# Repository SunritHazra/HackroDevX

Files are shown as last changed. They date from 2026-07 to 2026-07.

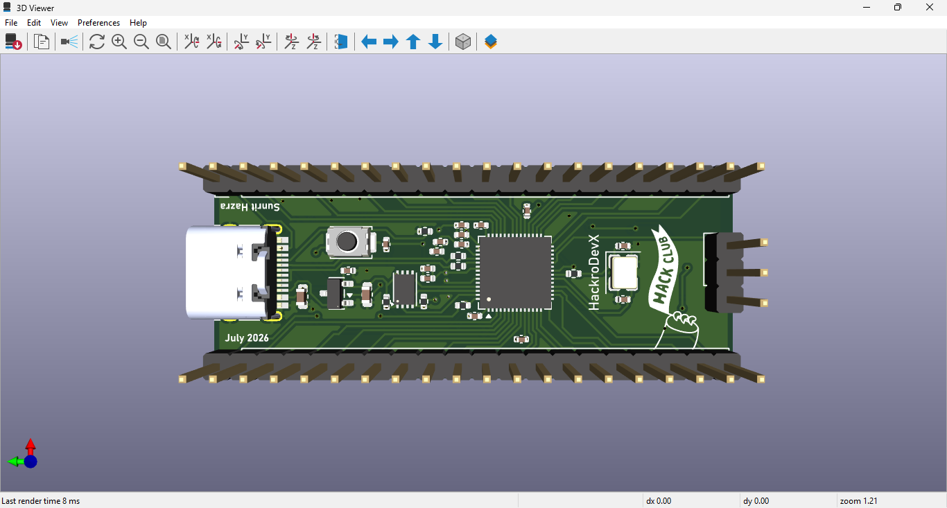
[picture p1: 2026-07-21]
Gallery/KiCad PCBA Render.png

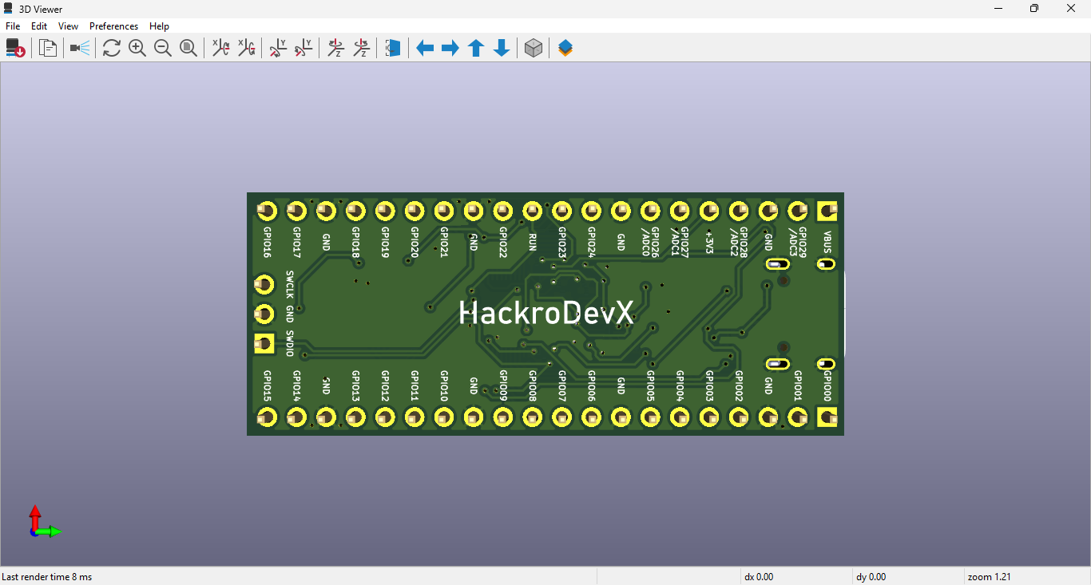
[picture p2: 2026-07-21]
Gallery/KiCad PCBA Back Side.png

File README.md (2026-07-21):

# HackroDevX

An open-source RP2040 development board with USB-C power/programming, onboard QSPI flash, and a Raspberry Pi Pico-compatible pinout. Built by following Hack Club's ["Custom Devboard"](https://blueprint.hackclub.com/starter-projects/devboard) starter project guide, entirely in KiCad. This is my first custom PCB from schematic to fabrication.

> Full day-by-day design log, decisions, and mistakes: [Engineering Log.md](https://github.com/SunritHazra/HackroDevX/blob/main/Engineering%20Log.md) (see also [JOURNAL.md](https://github.com/SunritHazra/HackroDevX/blob/main/JOURNAL.md) and [Fabrication Log.md](https://github.com/SunritHazra/HackroDevX/blob/main/Fabrication%20Log.md))

**Project stats:** 5 build-log days · ~25h 00m total design time · 100% designing progress, 0% building progress (as of the latest journal entry — board is ordered for PCBA, not yet assembled)

**On the name:** Follows the author's personal naming convention for electronics projects — "Hackro" as the base word, a short form of the project's defining trait ("Dev", for devboard), and a single trailing letter — giving **HackroDevX**.

---

## Renders

### Top View



### 45° View



### Bottom Corner View



---

## Hardware Architecture

### 1. Electrical Schematic

Full Schematic



The schematic follows the five functional blocks the guide breaks a devboard into: power/decoupling, USB-C, the crystal oscillator, QSPI flash storage, and the I/O breakout, all wired around a central RP2040.

**Power & decoupling:** One 0.1uF decoupling capacitor per RP2040 VDD pin — eight on the 3.3V IOVDD rail, two on the 1.1V DVDD rail — plus a 1uF bulk capacitor on each rail to smooth larger ripples. Power labels face up, ground labels face down, per standard schematic convention. [This](https://github.com/user-attachments/assets/96dde608-219d-472a-9682-96a95f16b071) is the power and decopuling.

**USB-C & step-down:** A USB-C receptacle with SHIELD/GND tied to ground, CC1/CC2 pulled down through 5.1KΩ resistors so the port negotiates power delivery, and the D+/D- lines routed through 27Ω termination resistors into the RP2040's USB_DP/USB_DM pins (set to bidirectional global labels). VBUS is stepped down from 5V to 3.3V using an **MCP1700x-330xxTT** LDO (swapped in from the guide's larger NCP1117-3.3_SOT223 for a smaller footprint, at the cost of a lower 250mA current limit), with 10uF bulk capacitors bracketing it. [This](https://github.com/user-attachments/assets/9e6f4866-57e1-4350-a7fc-b4eadb88d3cd) is the USB-C and step down.

**Crystal oscillator:** A 12MHz crystal (Y1) with two load capacitors on its I/O pins (bumped from the guide's 15pF to 33pF to match the load capacitance of the specific crystal part used), pins 2/4 tied to GND, and a 1KΩ damping resistor on XOUT to protect the crystal and keep the clock signal clean. [This](https://github.com/user-attachments/assets/4e26f85b-4016-400b-a56b-7d17701c3016) is the crystal ossilator.

**QSPI flash:** Since the RP2040 has no onboard flash, a quad-SPI flash IC is wired up with global labels matching the RP2040's QSPI pins, a 0.1uF decoupling cap on VCC, a 10KΩ pull-up on CS, and a BOOTSEL push button in series with a 1KΩ current-limiting resistor to GND — dropping the board into BOOTSEL/mass-storage mode on boot. [This](https://github.com/user-attachments/assets/fbd2d72e-f6a8-4ca6-835c-226b7e35d64e) is the onboard QSPI flash.

**I/O breakout:** TESTEN tied to GND (factory-test-only pin), and every remaining GPIO plus SWCLK/SWDIO broken out across two 1x20 headers and one 1x3 header, laid out to match the Raspberry Pi Pico pinout. VSYS, 3V3_EN, and ADC_VREF were skipped since there's no battery support, freeing up pins for extra GPIOs — including GPIO29 (ADC-capable) in place of the unused GPIO25. [This](https://github.com/user-attachments/assets/0c8a8f67-9cef-4537-8e4d-47fdbf4ebf10) is the I/O pins broken out.

### 2. Footprints

- **RP2040:** `QFN-56-1EP_7x7mm_P0.4mm_EP3.2x3.2mm`, straight from the datasheet.
- **Decoupling capacitors:** `0402` for all small signal capacitors.
- **Decopuling resistors:** `0402` for all small resistors.
- **Bulk (10uF) capacitors:** `0603`, for the extra physical room they need.
- **USB-C receptacle:** `USB_C_Receptacle_HRO_TYPE-C-31-M-12` — JLCPCB has no true basic-library USB-C part.
- **Header pins:** `PinHeader_1x20_P2.54mm_Vertical` (×2) and `PinHeader_1x03_P2.54mm_Vertical`.
- **Boot button:** `SW_Push_SPST_NO_Alps_SKRK`, a compact SMD footprint in JLCPCB's basic library.
- **Crystal:** `Crystal_SMD_3225-4Pin_3.2x2.5mm`, also a JLCPCB basic part — pin 1/3 orientation double-checked against the datasheet.
- **LDO:** `MCP1700x-330xxTT` (SOT-23), swapped from the NCP1117 for size.
- **Flash:** `W25Q16JVZPIQ TR` in the `Winbond_USON-8-1EP_3x2mm_P0.5mm_EP0.2x1.6mm` package — the same flash chip used on the real Pi Pico, swapped from the datasheet's larger W25Q128JVS.

### 3. Printed Circuit Board Assembly

Designed for rugged reliability and high-profile ergonomics using the custom footprints above.

KiCad PCB Window



KiCad PCB Render



KiCad PCBA Render



KiCad PCB Back Side



KiCad PCBA Back Side



- **Design files:** [`/PCBA`](./PCBA)

## Design Notes

**Board Size:** The board outline follows the guide's Pico-shaped form factor, sized **21mm × 51.5mm** (slightly longer than the guide's reference 21×51mm outline).

**Crystal load capacitance:** swapping to a different crystal part than the guide's reference meant the load capacitors had to be bumped from 15pF to 33pF to match its datasheet load capacitance.

**ERC net conflict:** an early wiring mistake merged the LDO's output and the RP2040's VREG_VOUT onto the same net (both flagged as power outputs), caused by using a slightly different LDO symbol than the guide's. Fixed by re-tracing the actual intended connections.

**Differential pair skew:** the USB D+/D- traces were initially routed without matching their lengths, resulting in a 6.5mm+ mismatch against a ~0.2mm budget — fixed by rerouting them as a proper differential pair.

**Silkscreen:** reference designators and values were batch-moved from the `F.Fab` layer to `F.Silkscreen` using KiCad's footprint text field batch update (filtered by layer, applied to functional text items). Less-useful `C#`/`R#` labels on small passives were deleted for a cleaner look, and bottom-side GPIO labels were checked for correct mirroring/orientation. The Hack Club "Orpheus" flag logo was thresholded through KiCad's Image Converter and placed on the silkscreen next to a `HackroDevX` text label and the author's name.**Silkscreen:** reference designators and values were batch-moved from the `F.Fab` layer to `F.Silkscreen` using KiCad's footprint text field batch update (filtered by layer, applied to functional text items). Less-useful `C#`/`R#` labels on small passives were deleted for a cleaner look, and bottom-side GPIO labels were checked for correct mirroring/orientation. The Hack Club "Orpheus" flag logo was thresholded through KiCad's Image Converter and placed on the silkscreen next to a `HackroDevX` text label and the author's name.

---

## Fabrication

- **Electrical Rule Check (ERC)** run after the schematic was completed.
- **Design Rule Check (DRC)** run after routing and ground pour, with thermal-relief/clearance errors resolved before export.
- **Gerber export:** full fabrication output (gerbers, drill files, footprint position files) exported from KiCad `9.0.7`.
- **CPL/BOM formatting for JLCPCB:** the CPL (`top-pos`) file headers were renamed `Ref → Designator`, `PosX → Mid X`, `PosY → Mid Y`, `Rot → Rotation`, `Side → Layer`, and the BOM's `Designation` column renamed to `Comment`, per JLCPCB's expected format.
- **Ordered:** production zip uploaded to JLCPCB with PCBA added for a batch of 5 assembled boards. Most parts auto-matched (RP2040 QFN-56, MCP1700x-330xxTT, USB-C receptacle, crystal, resistors, caps); the flash memory needed a manual match to JLCPCB's in-stock `W25Q16JVUXQTR` (functionally equivalent to the designed `W25Q16JVZPIQ TR`). Pin headers were left off the assembled parts list to hand-solder separately instead of paying per-part assembly fees.

Design files: [`/PCBA`](https://github.com/SunritHazra/HackroDevX/tree/main/PCBA)

---

## Bill of Materials (BOM)

JLCPCB BOM



JLCPCB BOM Tool - BOM Matching



Full sourcing sheet: [`/Bill of Materials`](https://github.com/SunritHazra/HackroDevX/tree/main/Bill%20of%20Materials)

### Electronics & PCB (SMD)

- **1x** PCB (21mm × 51.5mm, Pico-shaped outline)
- **1x** Raspberry Pi RP2040 SoC (QFN-56)
- **1x** W25Q16JVZPIQ TR QSPI flash memory
- **1x** MCP1700x-330xxTT LDO (3.3V, SOT-23)
- **1x** USB-C receptacle (HRO TYPE-C-31-M-12)
- **1x** 12MHz crystal oscillator (SMD 3225-4Pin)
- **1x** SPST push button (BOOTSEL)
- Decoupling capacitors (0402: 0.1uF ×10, 1uF ×2), bulk capacitors (0603: 10uF ×2), termination resistors (27Ω ×2), pull-up/pull-down/damping resistors (5.1KΩ, 10KΩ, 1KΩ)

### Hardware (THT)

- **2x** `PinHeader_1x20_P2.54mm_Vertical`
- **1x** `PinHeader_1x03_P2.54mm_Vertical`

### Sourcing

| Component | Vendor  |
| --- | --- |
| PCB Fabrication & PCBA | JLCPCB  |

JLCPCB Order



--

## AI as a Research & Documentation Aid

The schematic, footprint selection, PCB layout, routing, and all fabrication decisions were done manually by following the Hack Club guide and the RP2040 datasheet. AI tools were used only in a supporting role — for example, researching general approaches to fixing a stubborn DRC thermal-relief/clearance error, and for helping structure and write up this documentation.

> **Project Integrity:** All schematic wiring, footprint selection, PCB routing, and fabrication file prep were done manually in KiCad by following the Hack Club Devboard guide and the RP2040 datasheet. AI was used only for research, troubleshooting suggestions, and documentation help.

---

## License

This project is licensed under the MIT License — see the [LICENSE](https://github.com/SunritHazra/HackroDevX/blob/main/LICENSE) file for details.

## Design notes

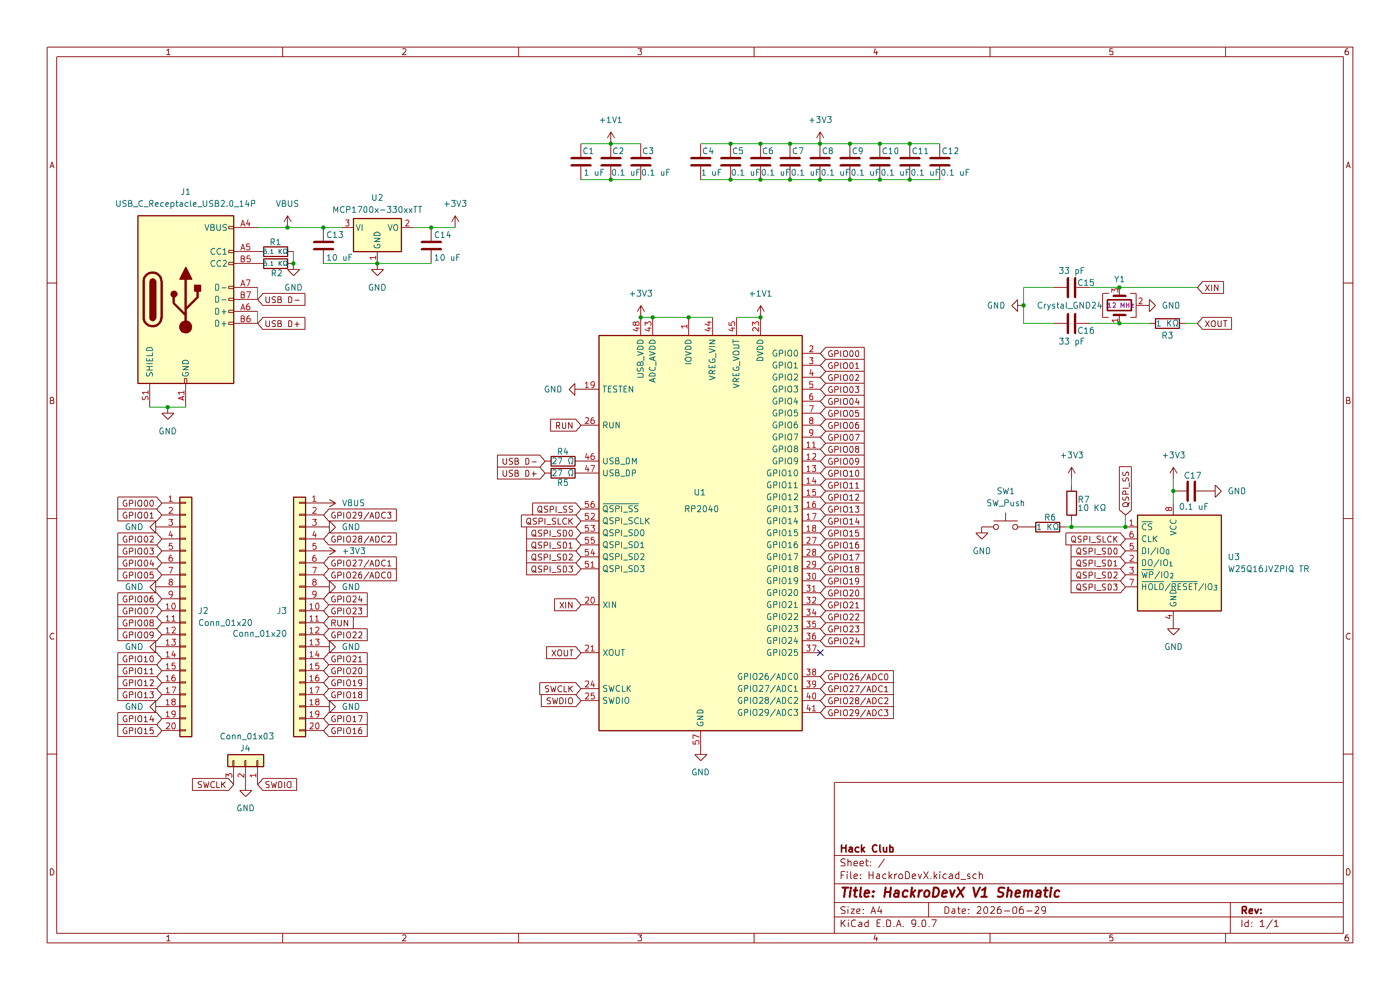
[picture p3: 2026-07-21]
Gallery/Schematic.png

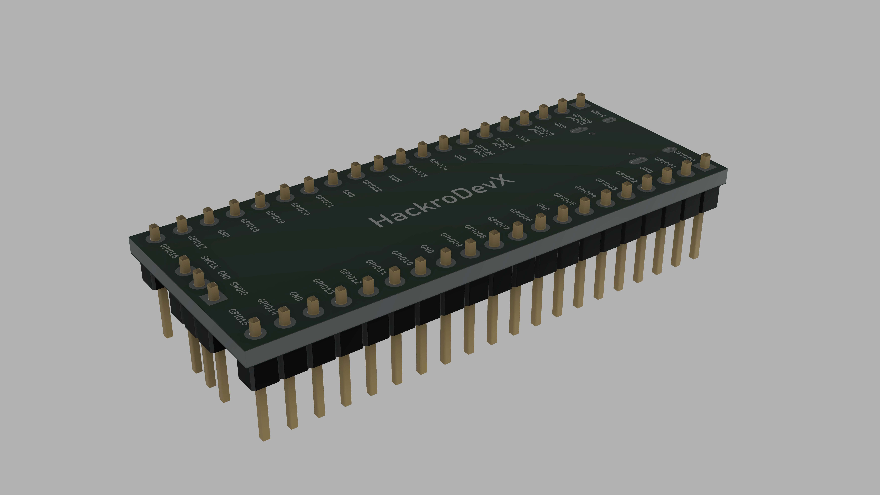
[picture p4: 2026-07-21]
Gallery/Bottom Corner View.png

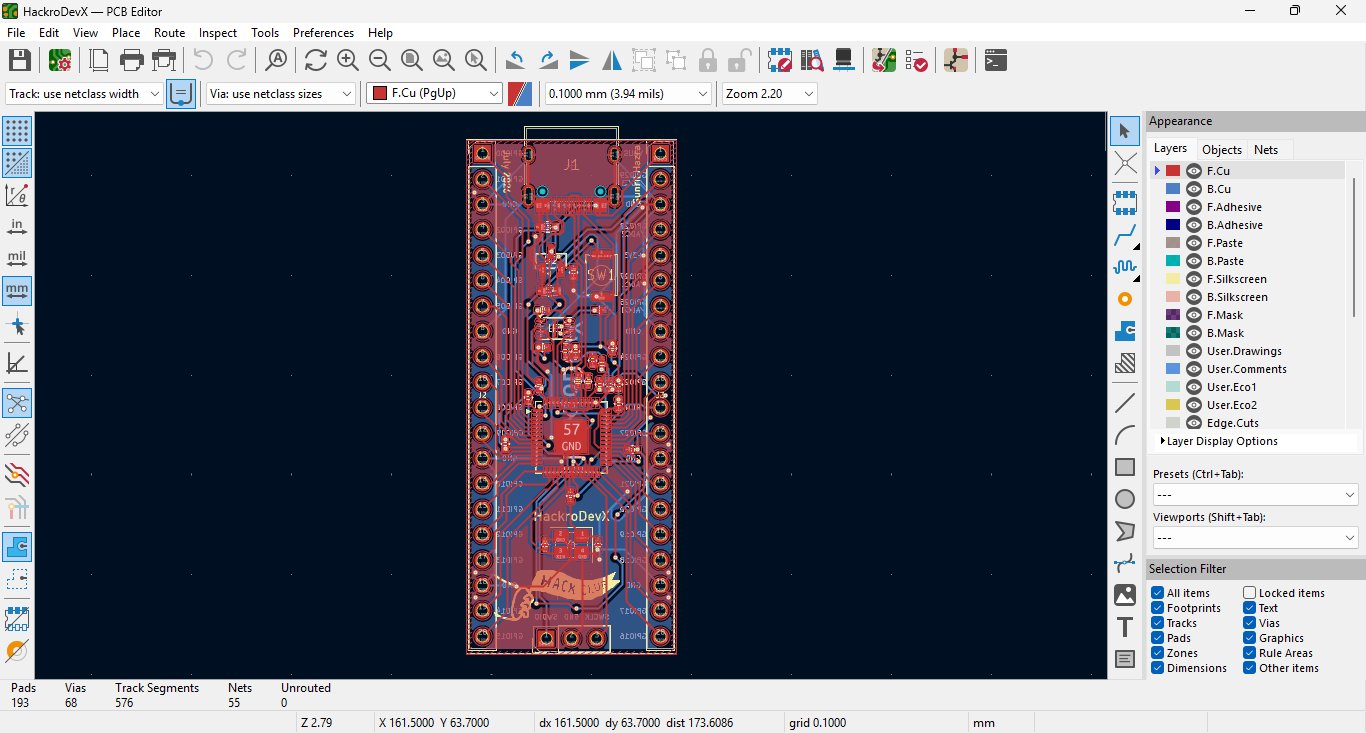
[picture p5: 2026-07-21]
Gallery/KiCad PCB Window.png

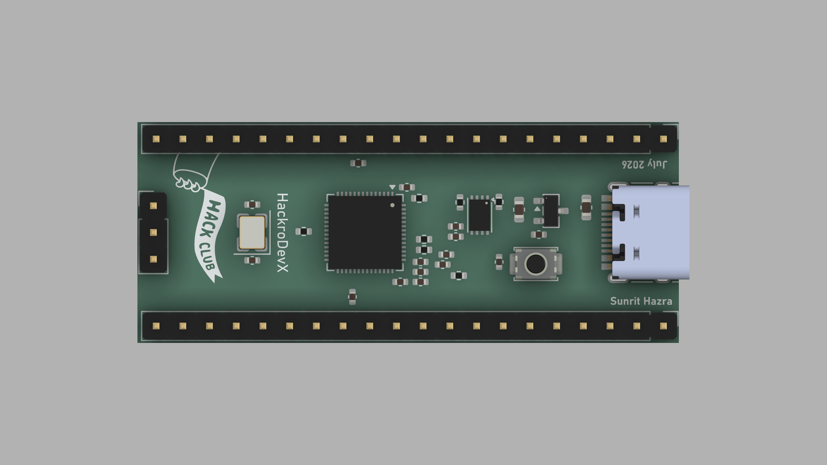
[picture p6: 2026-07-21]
Gallery/Top View.png

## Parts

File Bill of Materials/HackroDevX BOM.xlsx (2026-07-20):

HackroDevX BOM
Component Category | Item | Cost | Side Note | Link
PCBA | PCB [5] | $16.40 | No assembly
 | Total | $16.40
 | E-POST Shipping | $16.73 | Cheapest Option
 | Total | $16.73
Grand Total |  | #REF!

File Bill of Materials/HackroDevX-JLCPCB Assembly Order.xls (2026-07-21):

JLCPCB BOM Tool - BOM Matching
BOM name：HackroDevX-JLCPCB Assembly Order.xlsx |  |  | Download Time：2026-07-21 12:17:04 |  |  |  | * Our matching results are updated in real-time, but stock and prices may change. If it's been over 24 hours, please re-match before placing your order.
PCB Assembled Qty：5 |  |  | Est. Total Price：9.5271
Your BOM |  |  |  |  | Matched Parts |  |  |  |  |  |  | Order Information
Top Designator | Bottom Designator | Comment | Footprint | JLCPCB Part # | Matches | Part # | Manufacturer | Footprint | Description | Category | Warning | JLCPCB Part # | Product link | Lib Type | Qty | Source | Total Price ($)
C1,C4 |  | 1uF | C_0402_1005Metric |  | Select by Customer | CL05A105KP5NNNC | Samsung Electro-Mechanics | 0402 | 10V 1uF X5R ±10% 0402 Multilayer Ceramic Capacitors MLCC - SMD/SMT ROHS | Multilayer Ceramic Capacitors MLCC - SMD/SMT |  | C14445 | https://jlcpcb.com/partdetail/15107-CL05A105KP5NNNC/C14445 | Extended | 20 | 20 JLCPCB | 0.282
C2,C10,C9,C7,C3,C6,C11,C12,C5,C17,C8 |  | 0.1uF | C_0402_1005Metric |  | Select by Customer | CL05B104KO5NNNC | Samsung Electro-Mechanics | 0402 | 100nF 16V X7R ±10% 0402 Multilayer Ceramic Capacitors MLCC - SMD/SMT ROHS | Multilayer Ceramic Capacitors MLCC - SMD/SMT | 1.The comment (CL05B104KO5NNNC) of this part does not match the one (0.1uF) provided in your BOM. Please confirm; | C1525 | https://jlcpcb.com/partdetail/1877-CL05B104KO5NNNC/C1525 | Basic | 22 | 22 JLCPCB | 0.1166
C13,C14 |  | 10uF | C_0603_1608Metric |  | Select by Customer | CL10A106MQ8NNNC | Samsung Electro-Mechanics | 0603 | 10uF 6.3V X5R ±20% 0603 Multilayer Ceramic Capacitors MLCC - SMD/SMT ROHS | Multilayer Ceramic Capacitors MLCC - SMD/SMT |  | C1691 | https://jlcpcb.com/partdetail/2043-CL10A106MQ8NNNC/C1691 | Extended | 20 | 20 JLCPCB | 0.678
C15,C16 |  | 33pF | C_0402_1005Metric |  | Select by Customer | 0402CG330J500NT | FH (Guangdong Fenghua Advanced Tech) | 0402 | 33pF 50V C0G ±5% 0402 Multilayer Ceramic Capacitors MLCC - SMD/SMT ROHS | Multilayer Ceramic Capacitors MLCC - SMD/SMT |  | C1562 | https://jlcpcb.com/partdetail/1914-0402CG330J500NT/C1562 | Basic | 4 | 4 JLCPCB | 0.0564
J1 |  | USB_C_Receptacle_USB2.0_14P | USB_C_Receptacle_HRO_TYPE-C-31-M-12 |  | Select by Customer | TYPE-C-31-M-12 | Korean Hroparts Elec | SMD | -30℃~+80℃ 1 10,000 cycles 16P 20V 5A 7.35mm Female Surface Mount, Right Angle Type-C SMD USB Connectors ROHS | USB Connectors |  | C165948 | https://jlcpcb.com/partdetail/Korean_HropartsElec-TYPE_C_31_M12/C165948 | Extended | 2 | 2 JLCPCB | 0.3686
R2,R1 |  | 5.1K惟 | R_0402_1005Metric |  | Select by Customer | 0402WGF5101TCE | UNI-ROYAL(Uniroyal Elec) | 0402 | -55℃~+155℃ 5.1kΩ 50V 62.5mW Thick Film Resistor ±1% ±100ppm/℃ 0402 Chip Resistor - Surface Mount ROHS | Chip Resistor - Surface Mount |  | C25905 | https://jlcpcb.com/partdetail/26648-0402WGF5101TCE/C25905 | Basic | 4 | 4 JLCPCB | 0.0056
R4,R5 |  | 27惟 | R_0402_1005Metric |  | Select by Customer | 0402WGJ0270TCE | UNI-ROYAL(Uniroyal Elec) | 0402 | -55℃~+155℃ 27Ω 50V 62.5mW Thick Film Resistor ±100ppm/℃ ±5% 0402 Chip Resistor - Surface Mount ROHS | Chip Resistor - Surface Mount |  | C25156 | https://jlcpcb.com/partdetail/25899-0402WGJ0270TCE/C25156 | Extended | 20 | 20 JLCPCB | 0.026
R6,R3 |  | 1K惟 | R_0402_1005Metric |  | Select by Customer | 0402WGF1001TCE | UNI-ROYAL(Uniroyal Elec) | 0402 | -55℃~+155℃ 1kΩ 50V 62.5mW Thick Film Resistor ±1% ±100ppm/℃ 0402 Chip Resistor - Surface Mount ROHS | Chip Resistor - Surface Mount | 1.The comment (0402WGF1001TCE) of this part does not match the one (1K惟) provided in your BOM. Please confirm; | C11702 | https://jlcpcb.com/partdetail/12256-0402WGF1001TCE/C11702 | Basic | 4 | 4 JLCPCB | 0.032
R7 |  | 10K惟 | R_0402_1005Metric |  | Select by Customer | 0402WGF1002TCE | UNI-ROYAL(Uniroyal Elec) | 0402 | -55℃~+155℃ 10kΩ 50V 62.5mW Thick Film Resistor ±1% ±100ppm/℃ 0402 Chip Resistor - Surface Mount ROHS | Chip Resistor - Surface Mount | 1.The comment (0402WGF1002TCE) of this part does not match the one (10K惟) provided in your BOM. Please confirm; | C25744 | https://jlcpcb.com/partdetail/26487-0402WGF1002TCE/C25744 | Basic | 2 | 2 JLCPCB | 0.0152
SW1 |  | SW_Push | SW_Push_SPST_NO_Alps_SKRK |  | Select by Customer | TS-1088-AR02016 | XUNPU | SMD,4x3mm | -30℃~+80℃ 1.6N 100,000 cycles 12V 2mm 3.9mm 3mm 50mA Black Round Button SMD(SMT) Tab SPST Surface Mount,Vertical Without Bracket SMD,4x3mm Tactile Switches ROHS | Tactile Switches |  | C720477 | https://jlcpcb.com/partdetail/XUNPU-TS_1088AR02016/C720477 | Basic | 2 | 2 JLCPCB | 0.1104
U1 |  | RP2040 | QFN-56-1EP_7x7mm_P0.4mm_EP3.2x3.2mm |  | Select by Customer | RP2040 | Raspberry Pi | LQFN-56(7x7) | 12bit 133MHz 30 LQFN-56(7x7) Microcontrollers (MCU/MPU/SOC) ROHS | Microcontrollers (MCU/MPU/SOC) |  | C2040 | https://jlcpcb.com/partdetail/RaspberryPi-RP2040/C2040 | Extended | 2 | 2 JLCPCB | 1.9712
U2 |  | MCP1700x-330xxTT | SOT-23 |  | Select by Customer | MCP1700T-3302E/TT | Microchip Tech | SOT-23 | -40℃~+125℃@(Tj) 1 1.6uA 178mV@(250mA) 250mA 3.3V 44dB@(100Hz) 6V Fixed Over Temperature Protection、Short Circuit Protection Positive SOT-23 Voltage Regulators - Linear, Low Drop Out (LDO) Regulators ROHS | Voltage Regulators - Linear, Low Drop Out (LDO) Regulators |  | C39051 | https://jlcpcb.com/partdetail/MicrochipTech-MCP1700T_3302ETT/C39051 | Extended | 5 | 5 JLCPCB | 2.1035
U3 |  | W25Q16JVZPIQTR | Winbond_USON-8-1EP_3x2mm_P0.5mm_EP0.2x1.6mm |  | Select by Customer | W25Q16JVZPIQ TR | Winbond Elec | WSON-8-EP(5x6) | -40℃~+85℃ 100,000 cycles 10ms 10uA 120ms@(32KB) 133MHz 16Mbit 2.7V~3.6V 20 Years 400us SPI WSON-8-EP(5x6) NOR FLASH ROHS | NOR FLASH |  | C2456208 | https://jlcpcb.com/partdetail/WinbondElec-W25Q16JVZPIQTR/C2456208 | Extended | 2 | 2 JLCPCB | 3.5682
Y1 |  | Crystal_GND24 | Crystal_SMD_3225-4Pin_3.2x2.5mm |  | Select by Customer | X322512MSB4SI | YXC Crystal Oscillators | SMD3225-4P | -40℃~+85℃ 12MHz 20pF Crystal Oscillator ±10ppm ±20ppm SMD3225-4P Crystals ROHS | Crystals |  | C9002 | https://jlcpcb.com/partdetail/YXC_CrystalOscillators-X322512MSB4SI/C9002 | Basic | 2 | 2 JLCPCB | 0.1934
J2,J3 |  | Conn_01x20 | PinHeader_1x20_P2.54mm_Vertical |  | No matches | No Part Selected
J4 |  | Conn_01x03 | PinHeader_1x03_P2.54mm_Vertical |  | No matches | No Part Selected

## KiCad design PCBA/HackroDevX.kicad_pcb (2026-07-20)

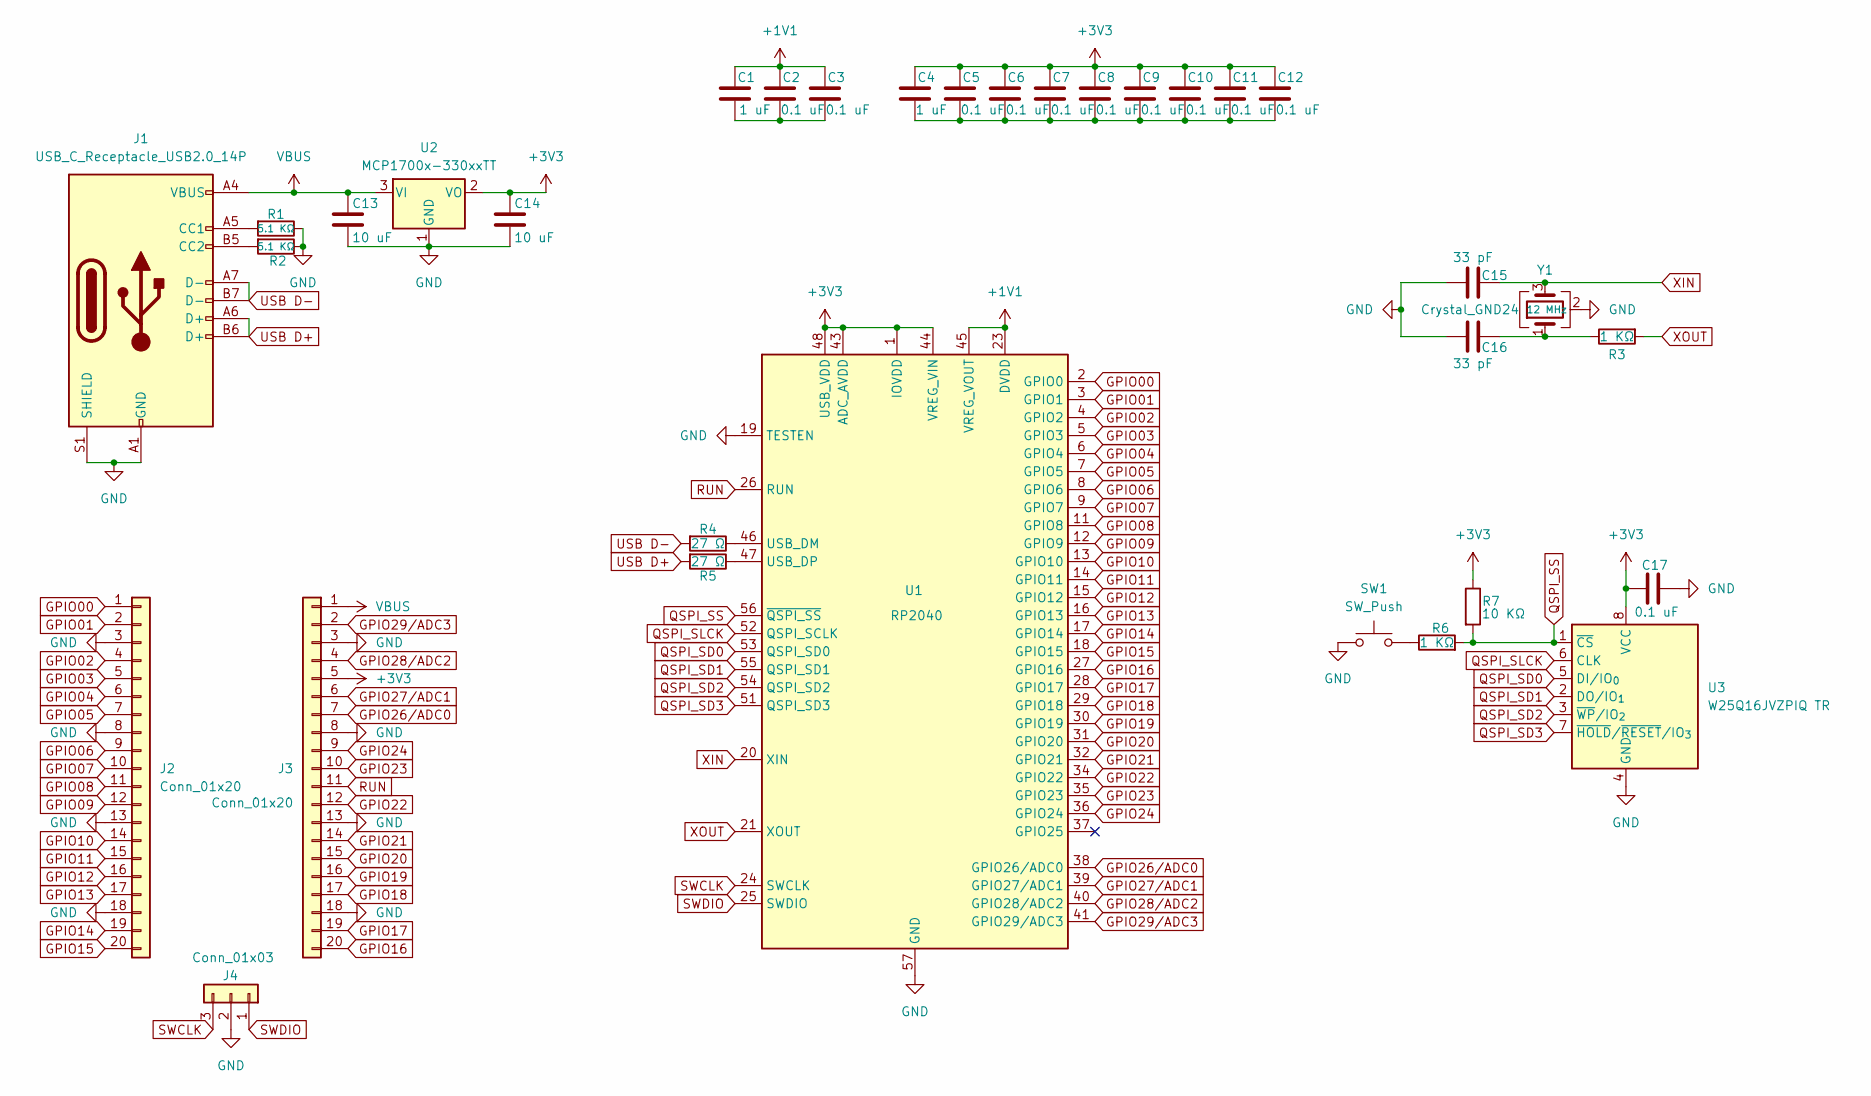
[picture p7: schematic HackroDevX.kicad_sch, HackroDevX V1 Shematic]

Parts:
C1, C4: 1 uF; C_0402_1005Metric
C2, C3, C5, C6, C7, C8, C9, C10, C11, C12, C17: 0.1 uF; C_0402_1005Metric
C13, C14: 10 uF; C_0603_1608Metric
C15, C16: 33 pF; C_0402_1005Metric
J1: USB_C_Receptacle_USB2.0_14P; USB_C_Receptacle_HRO_TYPE-C-31-M-12
J2, J3: Conn_01x20; PinHeader_1x20_P2.54mm_Vertical
J4: Conn_01x03; PinHeader_1x03_P2.54mm_Vertical
R1, R2: 5.1 KΩ; R_0402_1005Metric
R3, R6: 1 KΩ; R_0402_1005Metric
R4, R5: 27 Ω; R_0402_1005Metric
R7: 10 KΩ; R_0402_1005Metric
SW1: SW_Push; SW_Push_SPST_NO_Alps_SKRK
U1: RP2040; QFN-56-1EP_7x7mm_P0.4mm_EP3.2x3.2mm
U2: MCP1700x-330xxTT; SOT-23
U3: W25Q16JVZPIQ TR; Winbond_USON-8-1EP_3x2mm_P0.5mm_EP0.2x1.6mm
Y1: Crystal_GND24; Crystal_SMD_3225-4Pin_3.2x2.5mm

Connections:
+1V1: C1.1, C2.1, C3.1, U1.23 (DVDD), U1.45 (VREG_VOUT), U1.50 (DVDD)
+3V3: C4.1, C5.1, C6.1, C7.1, C8.1, C9.1, C10.1, C11.1, C12.1, C14.1, C17.1, J3.5, R7.1, U1.1 (IOVDD), U1.10 (IOVDD), U1.22 (IOVDD), U1.33 (IOVDD), U1.42 (IOVDD), U1.43 (ADC_AVDD), U1.44 (VREG_VIN), U1.48 (USB_VDD), U1.49 (IOVDD), U2.2 (VO), U3.8 (VCC)
GND: C13.2, C14.2, C15.1, C16.1, C17.2, J1.A1 (GND), J1.A12 (GND), J1.B1 (GND), J1.B12 (GND), J1.S1 (SHIELD), J2.3, J2.8, J2.13, J2.18, J3.3, J3.8, J3.13, J3.18, J4.2, R1.1, R2.1, SW1.1, U1.19 (TESTEN), U1.57 (GND), U2.1 (GND), U3.4 (GND), Y1.2 (G), Y1.4 (G)
GPIO00: J2.1, U1.2 (GPIO0)
GPIO01: J2.2, U1.3 (GPIO1)
GPIO02: J2.4, U1.4 (GPIO2)
GPIO03: J2.5, U1.5 (GPIO3)
GPIO04: J2.6, U1.6 (GPIO4)
GPIO05: J2.7, U1.7 (GPIO5)
GPIO06: J2.9, U1.8 (GPIO6)
GPIO07: J2.10, U1.9 (GPIO7)
GPIO08: J2.11, U1.11 (GPIO8)
GPIO09: J2.12, U1.12 (GPIO9)
GPIO10: J2.14, U1.13 (GPIO10)
GPIO11: J2.15, U1.14 (GPIO11)
GPIO12: J2.16, U1.15 (GPIO12)
GPIO13: J2.17, U1.16 (GPIO13)
GPIO14: J2.19, U1.17 (GPIO14)
GPIO15: J2.20, U1.18 (GPIO15)
GPIO16: J3.20, U1.27 (GPIO16)
GPIO17: J3.19, U1.28 (GPIO17)
GPIO18: J3.17, U1.29 (GPIO18)
GPIO19: J3.16, U1.30 (GPIO19)
GPIO20: J3.15, U1.31 (GPIO20)
GPIO21: J3.14, U1.32 (GPIO21)
GPIO22: J3.12, U1.34 (GPIO22)
GPIO23: J3.10, U1.35 (GPIO23)
GPIO24: J3.9, U1.36 (GPIO24)
GPIO26/ADC0: J3.7, U1.38 (GPIO26/ADC0)
GPIO27/ADC1: J3.6, U1.39 (GPIO27/ADC1)
GPIO28/ADC2: J3.4, U1.40 (GPIO28/ADC2)
GPIO29/ADC3: J3.2, U1.41 (GPIO29/ADC3)
unnamed: C1.2, C2.2, C3.2
unnamed: C4.2, C5.2, C6.2, C7.2, C8.2, C9.2, C10.2, C11.2, C12.2
unnamed: C16.2, R3.1, Y1.1
unnamed: J1.A5 (CC1), R1.2
unnamed: J1.B5 (CC2), R2.2
unnamed: R6.1, SW1.2
unnamed: R4.1, U1.46 (USB_DM)
unnamed: R5.1, U1.47 (USB_DP)
QSPI_SD0: U1.53 (QSPI_SD0), U3.5 (DI/IO_{0})
QSPI_SD1: U1.55 (QSPI_SD1), U3.2 (DO/IO_{1})
QSPI_SD2: U1.54 (QSPI_SD2), U3.3 (~WP/IO_{2})
QSPI_SD3: U1.51 (QSPI_SD3), U3.7 (~HOLD/~RESET/IO_{3})
QSPI_SLCK: U1.52 (QSPI_SCLK), U3.6 (CLK)
QSPI_SS: R6.2, R7.2, U1.56 (~QSPI_SS), U3.1 (~CS)
RUN: J3.11, U1.26 (RUN)
SWCLK: J4.3, U1.24 (SWCLK)
SWDIO: J4.1, U1.25 (SWDIO)
USB D+: J1.A6 (D+), J1.B6 (D+), R5.2
USB D-: J1.A7 (D-), J1.B7 (D-), R4.2
VBUS: C13.1, J1.A4 (VBUS), J1.A9 (VBUS), J1.B4 (VBUS), J1.B9 (VBUS), J3.1, U2.3 (VI)
XIN: C15.2, U1.20 (XIN), Y1.3
XOUT: R3.2, U1.21 (XOUT)

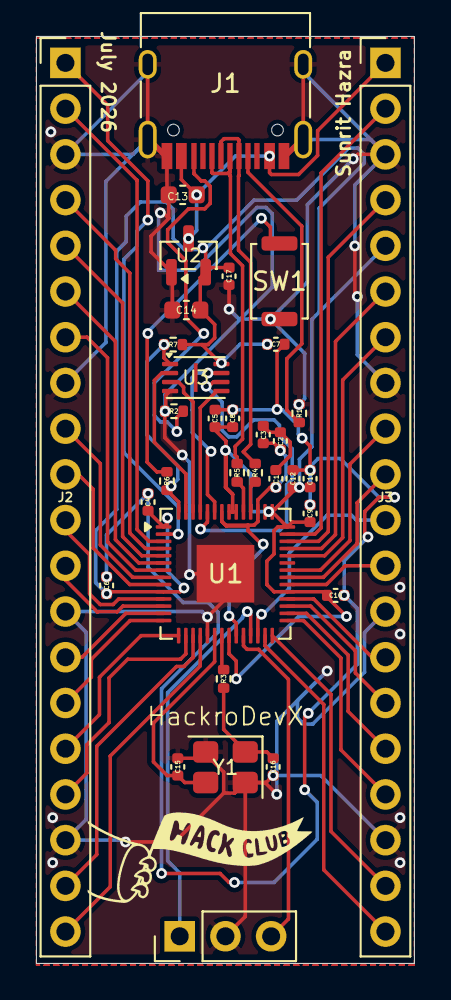
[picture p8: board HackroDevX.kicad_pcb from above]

Board: 2 copper layers, 21.0 x 51.5 mm, 33 parts (0 on the bottom side), 54 nets.

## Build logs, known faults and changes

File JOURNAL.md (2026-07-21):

---
**Title:** HackroDevX  
**Author:** Sunrit Hazra  
**Description:** A development board (devboard) based on Raspberry Pi RP2040 SoC with USB-C connectivity.
**Created on:** 2026-06-30  
**Designing Progress (%): 90%**
**Building Progress (%): 0%**
---

# Day 1 — 27.06.2026: Drawing the Schematic, Assigning Footprints & Placing Components

For the development board I have followed the Starter Project Guide from Hack Club Stasis. Before I started, I was thinking about what I can name my project. I guessed I could name it "HackroDevX"

In this naming system, there are three parts:

* The first phrase is a either a random word or "Hackro".
* The second phrase is a short phrase taken out of the thing's real name like "Dev", "Pad", or "Split".
* The third part is just a letter like "X" or somtehing else.

Thus giving the name "HackroPadX".

With the name confirmed, I opened KiCad and started reading the guide at the same time.

Here's how I did the schematic:

- First I placed down the RP2040 symbol in the center of the sheet, since it's the fundamental of the whole board.
- Then it was power and decoupling. The RP2040 has a bunch of VDD pins, so I placed one 0.1uF decoupling capacitor per power pin, eight of them for the 3.3V IOVDD line and two for the 1.1V DVDD line, plus a larger 1uF bulk capacitor on each of the two lines to smooth out bigger ripples. All power labels face upward and grounds face downward, as good schematic practice goes.
- Next was USB-C. I added a USB-C receptacle, wired SHIELD and GND to ground, and gave the D+/D- pins global labels since I'm only using one sheet. The CC1/CC2 pins got pulled down to GND through 5.1KΩ resistors so the port actually knows to deliver power.
- For stepping 5V down to 3.3V, the guide has you start with an NCP1117-3.3_SOT223 LDO, so that's what I placed first, with a 10uF bulk capacitor on either side of it, VBUS labeled before it and +3V3 labeled on its output.
- The USB D+/D- lines go into the RP2040's USB_DP/USB_DM pins through a pair of 27Ω termination resistors to stop signal distortion at high speed, and I made sure to set the D+/D- global labels to bidirectional since they carry data both ways.
- Then the crystal oscillator: a 12MHz crystal (Y1) with the standard two 15pF load capacitors on its I/O pins, pins 2 and 4 tied to GND, and a 1KΩ damping resistor on XOUT to protect the crystal and keep the signal clean. XIN/XOUT got global labels going to the RP2040.
- Since the RP2040 doesn't have any onboard flash, I added a W25Q128JVS quad-SPI flash IC and wired up all the QSPI pins (CLK, CS, and the four IO lines) with global labels matching the RP2040's QSPI pins, gave it a 0.1uF decoupling cap on VCC, and added a 10KΩ pull-up on the CS line plus a BOOTSEL push button in series with a 1KΩ current-limiting resistor down to GND, so the board can be dropped into BOOTSEL mode on boot.
- Last was breaking out the I/O. TESTEN got tied straight to GND since that pin's only for factory testing, and then I labeled every remaining GPIO along with SWCLK/SWDIO with their own names. I placed two 1x20 header symbols and one 1x3 header symbol laid out to match the Pi Pico pinout, since it's a pinout people are already used to. I skipped VSYS, 3V3_EN and ADC_VREF since I'm not adding battery support, and used the freed-up pins for extra GPIOs instead, including GPIO29 for the extra ADC-capable pin, no-connecting GPIO25 in its place.

* [This](https://github.com/user-attachments/assets/96dde608-219d-472a-9682-96a95f16b071) is the power and decopuling.
* [This](https://github.com/user-attachments/assets/9e6f4866-57e1-4350-a7fc-b4eadb88d3cd) is the USB-C and step down.
* [This](https://github.com/user-attachments/assets/4e26f85b-4016-400b-a56b-7d17701c3016) is the crystal ossilator.
* [This](https://github.com/user-attachments/assets/fbd2d72e-f6a8-4ca6-835c-226b7e35d64e) is the onboard QSPI flash.
* [This](https://github.com/user-attachments/assets/0c8a8f67-9cef-4537-8e4d-47fdbf4ebf10) is the I/O pins broken out.

Here's the full schematic:



With the schematic done, I ran ERC and got these 4 violations:



Three of them were the standard annoying "Input Power pin not driven by any Output Power pins" warning the guide already tells you to expect and ignore, since we know the LDO and the RP2040's own regulator are genuinely supplying those rails. The fourth flagged the RP2040's VREG_VOUT pin and the LDO's output pin as two power outputs sitting on the same net, which I made a mental note of to keep an eye on, since that's not one of the errors the guide tells to ignore. It happened I kind of messed up some of the wiring as the symbol I was using was a little different from what was shown in the guide.

This is my mistake:



And I fixed it carefully by understanding what the connections meant.



Next came footprints. For the most part I stuck close to what the guide uses, since JLCPCB's basic/extended part split makes a lot of these decisions for you anyway:

- **RP2040:** QFN-56-1EP_7x7mm_P0.4mm_EP3.2x3.2mm, straight off the datasheet.
- **Decoupling capacitors and resistors:** 0402 for all the small signal caps and resistors, since anything smaller gets hard to hand-place and 0402 is plenty stable for low current.
- **10uF bulk capacitors:** 0603, since they need a bit more room than the tiny 0402 footprint comfortably allows.
- **USB-C receptacle:** USB_C_Receptacle_HRO_TYPE-C-31-M-12, since JLCPCB doesn't have a true basic-library USB-C part.
- **Header pins:** PinHeader_1x20_P2.54mm_Vertical for the two side headers and PinHeader_1x03_P2.54mm_Vertical for the extra 3-pin header.
- **Boot button:** SW_Push_SPST_NO_Alps_SKRK, a compact SMD footprint sitting in JLCPCB's basic library, so it doesn't add anything to the assembly cost.
- **Crystal:** Crystal_SMD_3225-4Pin_3.2x2.5mm, also a JLCPCB basic part. I double-checked the footprint's pin 1/3 orientation against the datasheet since it's really easy to get a crystal's pinout backwards.
- **LDO:** switched from the NCP1117-3.3_SOT223 to the smaller MCP1700x-330xxTT in a SOT-23 package. It only handles 250mA instead of the NCP1117's much larger current, but that's more than enough headroom for the devboard.
- **Flash:** switched to the W25Q16JVZPIQ TR in the Winbond_USON-8-1EP_3x2mm_P0.5mm_EP0.2x1.6mm package, the same smaller flash chip the actual Pi Pico itself uses, instead of the bigger W25Q128JVS from the datasheet.

Because I swapped in a different crystal than the guide's reference part, its load capacitance was slightly different, so I bumped the two load capacitors from 15pF up to 33pF to match.

With footprints assigned, I switched over to the PCB editor and hit F8 to update the PCB from the schematic. I drew the board outline next: the guide uses a compact **21×51mm** Pico-shaped outline, but I gave myself more breathing room (length) unintentionally and sized mine at **21mm × 51.5mm** instead.

From there I placed the two big 1x20 headers using Positioning Tools against the board's corners, then placed the RP2040 dead center then moved it a little down, the USB-C connector up near the top edge, the LDO close to VBUS, the flash memory right next to the RP2040's QSPI pins, and the crystal tight against XIN/XOUT with its load caps and damping resistor sitting right beside it. Then I went through and grouped all the decoupling caps next to whichever pins they were actually decoupling, RP2040 caps together, LDO bulk caps together, and so on.

By the end of the day I had every component placed except some capacitors and resistors and the board outline drawn, but nothing routed yet.

Here's the lapse of today's session: [HackroDevX-LPS-1-D1](https://lapse.hackclub.com/timelapse/FK_UCOY82zEO)

**Total time spent: 3h 15m**

---

# Day 2 — 28.06.2026: Routing

Today was all about routing. I started, like the guide suggests, with the flash memory's QSPI signals, since those are simple, short, low-speed traces and a good warm-up, temporarily moving the nearby decoupling caps out of the way so I had room to work.

Then came the part I was most careful with: the USB-C differential pair. I routed them randomly without realising the mistake I was making. I fixed my mistake on Day 4 by routing two D+ pins and two D- pins on the connector together first, then routed them from the USB-C connector, through the 27Ω termination resistors, and into the RP2040's USB_DP/USB_DM pins, leaving a gap inside the pair for the decoupling caps to sit in later.

I then went through and routed the rest of the RP2040's decoupling caps, the crystal's load caps and damping resistor, the USB-C CC pulldowns, and the button pull-up resistor, switching between the front copper layer for vertical-ish runs and the back copper layer (with vias where I needed to hop layers) for the rest, roughly following the guide's suggestion of routing front signals vertically and back signals horizontally where it made sense.

Back on my own board, I spent the rest of the night wiring up the header pin nets one by one, working through the GPIO breakout, and got a good chunk of the power distribution (VBUS/GND/+3V3) routed to the main cluster of components too. I left the boot button and its associated traces for later, since like the guide says, there's no one specific spot it needs to be, so it's an easy thing to slot in wherever there's room left in the devboard.

By the end of the day I had roughly half the board routed, with the fast USB signals, the flash memory, the crystal, and most of the decoupling done, and the header pins and remaining power distribution still to go.

Here's a glimpse of what I had achieved by the end of the day:



Here're the lapses of today's session: [HackroDevX-LPS-2-D2-1](https://lapse.hackclub.com/timelapse/aFMjs7GqHVZj) and [HackroDevX-LPS-2-D2-2](https://lapse.hackclub.com/timelapse/7HHVShKjE44z)

**Total time spent: 2h 20m**

---

# Day 3 — 29.06.2026: Completing the Routing & Exporting PCB

Today I finished off the rest of the routing, working through the remaining header pin nets and finishing power distribution out to the pins further from the main cluster, until there were zero unrouted nets left on the board. It was really exhausting and also ironically fun at the same time. The feeling: with every net, I was a step closer to `0` unconnected pins; is just undefinable.

With routing done, I added the ground fill: drew a filled zone across both copper layers, set the net to `GND`, and used thermal reliefs for the pad connections with a minimum spoke count of `2`, same as the guide walks through. Running DRC after that threw a handful of `Thermal relief connection to zone incomplete` errors on a few isolated pads, on the crystal, a couple of the header pins, and one of the load caps, exactly the kind of ground-pour headache the guide warns you about. I went into `Board Setup → Design Rules → Constraints` to see what my clearance and thermal relief settings actually were, and also asked Google's `AI Mode` how to fix a DRC clearance error, which laid out two general approaches:

- **Change the layout** — spread the offending traces apart with the push/shove router, manual dragging, or a full re-route.
- **Loosen the design rule constraints** — if your manufacturer can handle tighter tolerances.

I ended up re-filling the zones and adding a few extra vias onto the isolated ground islands to get everything properly connected to the pour.

Here's how the board looks after adding copper pours:



Next was silkscreen. I searched up how to batch-convert all the `F.Fab` layer text to silkscreen, since I had reference designators and values sitting on the fab layer that needed to move, and found that KiCad's footprint text field batch update lets you filter items by layer (set to `F.Fab`), tell it to apply to functional text items, and then change the target layer to `F.Silkscreen` in one go. After that I went through and manually cleaned things up further, deleting the less useful `C#`/`R#` labels for the tiny passives and keeping the important ones, and double-checked the bottom-side GPIO labels were mirrored and oriented properly so they'd actually read correctly from that side of the board.

Then it was time for a bit of art. I grabbed the Hack Club "Orpheus" flag logo from [here](https://hackclub.com/brand), ran it through KiCad's built-in Image Converter to threshold it down to black and white, and copied it to clipboard and exported it on the `F.Silkscreen` layer. I placed that near the crystal along with a `"HackroDevX"` text label and my name, so the board has a bit of personality on it.

I ran DRC one more time to make sure everything was clean, then went to `File → Fabrication Outputs` and exported everything (gerbers, drill files, footprint position files) with KiCad `9.0.7` into a `HackroDevX_Gerber` folder, keeping a `HackroDevX-backups` folder alongside it from earlier in the day. Following the guide, I opened the CPL (`top-pos`) file in Google Sheets and renamed the headers:

- `Ref` → `Designator`
- `PosX` → `Mid X`
- `PosY` → `Mid Y`
- `Rot` → `Rotation`
- `Side` → `Layer`

Since that's what JLCPCB expects, and did the same for the BOM file, renaming `Designation` to `Comment`. I zipped the whole gerber set into a production zip and uploaded it to JLCPCB's quote page, added PCBA to the order for a batch of `5` assembled boards, and uploaded the renamed BOM and CPL files.

Going through JLCPCB's part matching, most parts auto-matched fine, the `RP2040` QFN-56, the `MCP1700x-330xxTT`, the USB-C receptacle, the crystal, and the resistors and caps. The flash memory needed a manual nudge, JLCPCB had it in stock as `W25Q16JVUXQTR` rather than the exact `W25Q16JVZPIQ TR` from my design, which the guide actually mentions can happen since they're functionally the same part with minor differences. I made sure to leave the pin headers off the assembled parts list, since those are cheap enough and easy enough to hand-solder myself instead of paying JLCPCB's per-part assembly fee for them.

Here's the JLCPCB BOM:



With the BOM fully matched, I've landed at the JLCPCB cart, everything uploaded and matched, but not checked out yet.

Here's the lapse of today's session: [HackroDevX-LPS-3-D3](https://lapse.hackclub.com/timelapse/XPbqHUrSpcms)

**Total time spent: 6h 10m**

---

# Day 4 — 19.07.2026: Journaling & Fixing D-/D- Net Lengths

I mostly spent my time journaling days #1, #2, #3, and #4.

Day #1



Day #2



Day #3



**There are two imporatant things to be noted:**

1. I also fixed a major bottleneck of the project: the crazy length difference between the D+ and D- length. It was a whopping 6.5 mm+ in different and the maximum I could afford was 0.2 mm. At the time, I did not realize that it would have major drawback with the fast incoming data. Anyways, I fixed it by moving the switch a little to the right and unconnecting some nets. Then, using differential pair, I properly routed them and made sure that the difference between their length is minimal. With that ensured, I connected the things that I had moved and unrouted.

2. After the lapse [HackroDevX-LPS-4-D4-1](https://lapse.hackclub.com/timelapse/-wHSsLC3JRmy), I started another lapse where I logged Day 3 full. But unfortunately, the second lapse failed and didn't compile. The time I took for the failed session was roughly a little over one hour. Like, 1 hour 4 minutes or something.

Here're the lapses of today's session: [HackroDevX-LPS-4-D4-1](https://lapse.hackclub.com/timelapse/-wHSsLC3JRmy) and [HackroDevX-LPS-4-D4-2]()

**Total time spent: 5h 15m**

---

# Day 5 — 20.07.2026: Working on the Repository

Today was all about compiling the fruits of the last few days of work and making the project public-ready. I focused entirely on documentation, visual assets, and setting up the GitHub repository.

Here is exactly what went down today:

Visual Assets: Pulled clean screenshots of the completed schematic and PCB from KiCad — the full schematic sheet, the routed board with the ground fill, the silkscreen art, and the DRC/ERC results showing zero remaining errors. These visuals document the design exactly as it was sent off for fabrication.
Documentation (README.md): Wrote the comprehensive project README.md to serve as the landing page for the repository, covering the schematic breakdown, footprint choices, layout/routing decisions, the fabrication and JLCPCB ordering process, and the BOM. I used AI solely as a second set of eyes to help structure the write-up and clean up grammar and phrasing, making sure it still accurately reflects the actual design process from the Engineering Log.
Repository Setup & Licensing: Organized the local KiCad project files into the remote GitHub repository, split into folders for the Bill of Materials and the PCBA/Gerber outputs, kept the Engineering Log, Fabrication Log, and JOURNAL alongside them, and added an open-source MIT license to protect and share the work.

I also added a section in the README where I wrote about how I used AI in this project, in the section "AI as a Research & Documentation Aid".

Here's how far I have worked on the repository:



With this, the only things left incomplte are as follows:

- Adding images and renders.
- Completeing the Order by choosing components.

Here's the lapse of today's session: [HackroDevX-LPS-5-D5](https://lapse.hackclub.com/timelapse/kIgZJ82Pi4lN)

**Total time spent: 5h 20m**

---

# Day 6 — 21.07.2026: Adding Images & Re-confirming JLCPCB Cart

Today was the final day of the engineering process of this project.

Yesterday, I wrote the Readme, Journals and everything but I didn't add the images or even capture the renders needed for my project, out of my tiredness (and lazyness). Thus, today I added the images and renders, as well as completed the cart order by selecting all the components.



This is the screenshot of the order pending for payment, with a cost breakdown.



With the repository fully structured and the design phase sitting at 90%, HackroDevX is officially ready to move from an ordered PCBA to a physical, assembled board — the last 10% waiting on the boards to arrive and get soldered/tested.

Here's a screenshot of the repository itself:



Here's the lapse of today's session: [HackroDevX-LPS-6-D6]()

**Total time spent: 2h 40m**

---

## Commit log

2026-07-19 Revise journal entries for Days 1 and 2
    Updated the journal entry for Day 1 and Day 2, detailing schematic drawing, component placement, and routing processes.
2026-07-19 Finish routing and prepare files for fabrication
    Completed routing of all header pin nets and power distribution, added ground fill, and addressed DRC errors. Updated silkscreen and exported fabrication files for JLCPCB.
2026-07-20 Update README with BOM and AI usage details
    Added Bill of Materials and AI documentation section.
2026-07-20 final commit (probably)
    [HackroDevX BOM.xlsx, HackroDevX.csv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]
2026-07-21 Update README with JLCPCB BOM and order details
    Added images and information related to JLCPCB BOM and orders.
2026-07-21 Create HackroDevX-JLCPCB Assembly Order.xls
    [HackroDevX-JLCPCB Assembly Order.xls]
